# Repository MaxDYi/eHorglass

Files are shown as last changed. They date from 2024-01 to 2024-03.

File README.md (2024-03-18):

# 电子沙漏

# 0 目录

1. 简介
2. 原理图
3. PCB
4. 外壳
5. 物料清单
6. 成本核算
7. 代码实现
8. AT指令

# 1 简介

电子沙漏使用STM32F103C8T6作为主控，利用MPU6050感知当前重力方向。

- 支持使用AT指令对运行参数进行配置。
- 支持更换点阵颜色（更换LED8x8点阵屏）。
- 支持Typec接口充电（内置900mAh锂电池）。



# 2 原理图

eHorglass-SCH-V0.0

# 3 PCB





PCB使用4层板设计，面积4.6x9.2cm，主要元器件位于背面，正面仅有LED8x8点阵屏的圆形排母座。

# 4 外壳

外壳设计详见github库中的**4.Component**部分，共设计**外壳-上**与**外壳-上**两部分，使用3D打印进行实现，利用M3铜柱进行连接。

|  元件 | 尺寸 | 体积 |  表面积 |
| :-----: | :---: | :---: | :---: |
| 外壳-上 | 3.2 * 5.2 * 9.8cm  | 17.72cm³ | 245.49cm² |
| 外壳-下 | 3.45 * 5.2 * 9.8cm | 24.72cm³ | 289.86cm² |

# 5 物料清单

| Comment | Description | Designator | Footprint | Quantity |
| --- | --- | --- | --- | --- |
| 10uF | 贴片电容/MLCC电容 | C1, C2, C10, C12, C13 | C0603_M | 5 |
| 100nF | 贴片电容/MLCC电容 | C3, C4, C5, C6, C7,  C8, C9, C11, C14, C15, C16, C17, C18, C19 | C0603_M | 14 |
| 20pF | 贴片电容/MLCC电容 | C20, C21 | C0603_M | 2 |
| 1N5819 | 肖特基二极管 | D1, D2 | SOD-323 | 2 |
| TP4056 | 锂电池充电管理 | IC1 | SOIC-8_EP | 1 |
| Header 5X2 | 5*2P接插件 | JP1 | HDR2.54-LI-2x5P | 1 |
| HDR-1X2 | 2P接插件 | JP2 | XH2.54-LI-2P | 1 |
| 1588A | 共阴单色LED8*8点阵屏 | LD1, LD2 | LED 8*8-32-FH | 2 |
| RED | 贴片LED | LED1, LED3 | LED0603_R | 2 |
| GREEN | 贴片LED | LED2 | LED0603_G | 1 |
| AO3401 | P沟道 30V/4.2A | Q1 | SOT23-3N | 1 |
| 1K | 贴片电阻 | R1, R3, R11 | R0603_M | 3 |
| 2K | 贴片电阻 | R2 | R0603_M | 1 |
| 10K | 贴片电阻 | R4, R9, R10, R14 | R0603_M | 4 |
| 20K | 贴片电阻 | R5, R6 | R0603_M | 2 |
| 5.1K | 贴片电阻 | R7, R8 | R0603_M | 2 |
| 4.7K | 贴片电阻 | R12, R13 | R0603_M | 2 |
| KCD1-101 | 1路单刀船型开关 | S1 | HDR2.54-LI-2P | 1 |
| M3铜柱 | 铜柱 | SP1, SP2, SP3, SP4 | M3x20+6_N | 4 |
| 3x6x5 | 3x6轻触开关 | SW1 | SW SMD-3*6*2.5  | 1 |
| STM32F103C8T6 | STM32 ARM-based  32-bit MCU | U1 | LQFP48_N | 1 |
| MAX7219 | 8位 LED驱动器 | U2, U3 | SOIC-24W | 2 |
| MPU6050 | 三轴加速度+三轴陀螺仪 | U4 | QFN24-P50 | 1 |
| HT7533 | LDO线性稳压芯片 | U5 | SOT89_N | 1 |
| TYPE-C 2.0  -16P | USB2.0_Type-C_16Pin母座 | USBC1 | USB-C-SMD_16P | 1 |
| 8MHz | 2脚无源晶振(谐振器） | X1 | OSC-5032-2P | 1 |

# 6 成本核算

| 类目 | 型号 | 采购总价 | 采购数量 | 采购单价 | 使用数量 | 小计 |
| :---: | :---: | :---: | :---: | :---: | :---: | :---: |
| PCB |  四层板1.6mm厚 | ¥100.44  | 10 | ¥10.0440 | 1 | ¥10.04 |
| SMT | 经济型 | ¥133.06  | 10 | ¥13.3060 | 1 | ¥13.31 |
|  元器件  | STM32F103C8T6等  |  ¥8.69 | 1 | ¥8.6900  | 1 | ¥46.1 |
| 外壳 | 外壳（黑色树脂） |  ¥9.21 | 1 | ¥9.2100  | 1 | ¥18.50 |
|  固定件  | 尼龙M3固定件 |  ¥6.43 | 100 | ¥0.0643  | 4 | ¥0.67 |
|  锂电池  | 900mAh单节锂电池 |  ¥11.00  | 1 | ¥11.0000 | 1 | ¥11.00 |
| **合计** | | | | | | **¥99.63** |

# 7 代码实现

## 7.1 软件环境

IAR 9.30

STM32CubeMX 6.5.0

## 7.2 主要库

使用到的库位于**\eHorglass\Drivers**路径下。

| 库 | 功能 |
| --- | --- |
| AT | AT指令控制与应答 |
| MAX7219 | 点阵屏驱动库 |
| MPU6050 | MPU6050陀螺仪驱动 |
| parameter | 运行参数配置库 |
| Runtime | 获取代码段运行时间 |
| SandMove  | 砂砾运动控制核心算法 |

## 7.3 砂砾运动控制核心算法

算法流程图如下：

流程图

## 7.4 Flash使用

STM32F103C8T6共64KB内部FLASH，分为64Page，每Page为1KB。



使用前63个FLASH烧录App，最后一个FLash区域用于记录参数。

| 用途 | 地址 | 大小 |
| :---: | :---: | :--: |
| App | 0x08000000 - 0x0800FBFF | 63KB |
| Parameter | 0x0800FC00 - 0x0800FFFF | 1KB  |

最后一个FLash区域记录的参数表如下：

| 参数 | 字节数 |  格式  | 备注 |
| :---: | :----: | :----: | :---: |
| initFlag  | 4 | uint32 | 初始化标志 |
|  sandNum  | 4 | uint32 |  砂砾个数  |
| frameTime | 4 | uint32 | 帧间隔时间 |

# 8 AT指令

支持使用AT指令修改运行参数，可以修改与砂砾个数（SANDNUM）显示帧间隔（FRAMETIME）。

指令分为查询指令与写入指令，均以“**\r\n**”结尾。

## 8.1 使用说明

使用的是STM32的USB虚拟串口实现AT指令，无需设置波特率、数据位、校验位和停止位。

使用时先打开电源开关，再将USB线插入电脑USB口，可以在串口调试助手中读取到“**STMicroelectronics Virtual COM Port**”的串口，如无法打开则尝试重新插拔。

## 8.1 查询指令

查询指令共有3条。

- AT+INFO=?
- AT+SANDNUM=?
- AT+FRAMETIME=?

这3条指令分别返回系统信息、砂砾个数与帧间隔时间。

## 8.2 写入指令

写入指令共有2条。

- AT+SANDNUM=num（AT+SANDNUM=64）
- AT+FRAMETIME=num（AT+FRAMETIME=150）

其中，num为正整数。对于AT+SANDNUM，num的限定值为1-64；对于AT+FRAMETIME，num的限定值为20-1000。

写入后需要重启电源。

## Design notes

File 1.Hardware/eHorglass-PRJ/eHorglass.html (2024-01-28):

Reporting Options

# File in Newer Format

Date | : | 2024/1/27
Time | : | 14:37:39
Project name | : | E:\eHorglass\1.Hardware\eHorglass-PRJ\eHorglass.PrjPcb
Schematic documents | : | eHorglass.SchDoc

Version | Warning
22.3.0 | Custom diff pair suffixes are not supported in this version.

These files were generated in a later version of Altium Designer. Be aware that some data may have been added through functionality not available in your current version and will therefore not be available to you.

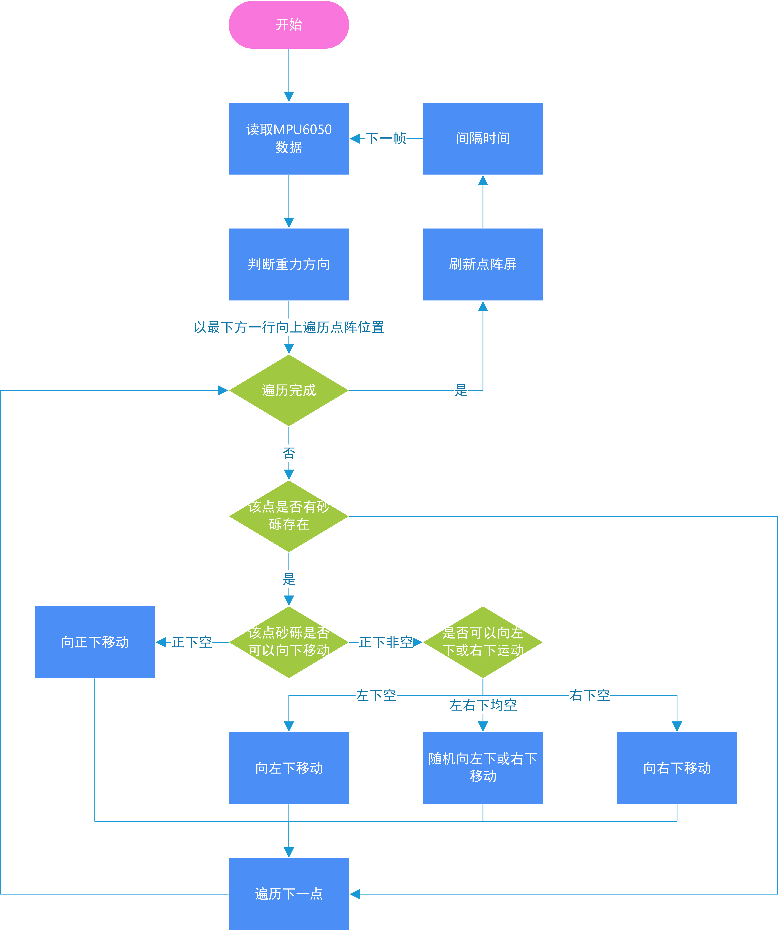
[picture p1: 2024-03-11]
5.Docs/算法流程图/流程图.png

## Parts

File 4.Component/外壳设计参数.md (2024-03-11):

# 外壳设计参数

船型开关开槽9.0x14.0mm

TYPEC开槽10.0x5.0mm

3D打印厚度1.5mm

底部外壳厚4.0mm

上部分外壳厚1.5mm

| 内容 | 高度 |
| --- | --- |
| 铜柱 | 20.0mm |
| 板厚 | 1.6mm  |
| 点阵 | 11.0mm |
| 冗余 | 0.4mm  |
| 上壳厚 | -1.5mm |
| 合计 | 31.5mm |

点阵屏外形尺寸



船型开关参数



TYPE-C接口尺寸



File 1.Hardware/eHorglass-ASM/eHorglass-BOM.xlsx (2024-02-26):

Comment | Description | Designator | Footprint | LibRef | Quantity
10uF | 贴片电容/MLCC电容 | C1, C2, C10, C12, C13 | C0603_M | C | 5
100nF | 贴片电容/MLCC电容 | C3, C4, C5, C6, C7, C8, C9, C11, C14, C15, C16, C17, C18, C19 | C0603_M | C | 14
20pF | 贴片电容/MLCC电容 | C20, C21 | C0603_M | C | 2
1N5819 | 肖特基二极管 | D1, D2 | SOD-323 | 1N5819 | 2
TP4056 | 锂电池充电管理 | IC1 | SOIC-8_EP | TP4056 | 1
Header 5X2 | 5*2P接插件 | JP1 | HDR2.54-LI-2x5P | Header 5X2 | 1
HDR-1X2 | 2P接插件 | JP2 | XH2.54-LI-2P | Header 2 | 1
1588A | 共阴单色LED8*8点阵屏 | LD1, LD2 | LED 8*8-32-FH | 1588A | 2
RED | 贴片LED | LED1, LED3 | LED0603_R | LED | 2
GREEN | 贴片LED | LED2 | LED0603_G | LED | 1
AO3401 | P沟道 30V/4.2A | Q1 | SOT23-3N | AO3401 | 1
1K | 贴片电阻 | R1, R3, R11 | R0603_M | R | 3
2K | 贴片电阻 | R2 | R0603_M | R | 1
10K | 贴片电阻 | R4, R9, R10, R14 | R0603_M | R | 4
20K | 贴片电阻 | R5, R6 | R0603_M | R | 2
5.1K | 贴片电阻 | R7, R8 | R0603_M | R | 2
4.7K | 贴片电阻 | R12, R13 | R0603_M | R | 2
1K5 | 贴片电阻 | R15 | R0603_M | R | 1
22R | 贴片电阻 | R16, R17 | R0603_M | R | 2
KCD1-101 | 1路单刀船型开关 | S1 | HDR2.54-LI-2P | KCD1-101 | 1
M3铜柱 | 铜柱 | SP1, SP2, SP3, SP4 | M3x20+6_N | 铜柱加头大焊盘 | 4
3x6x5 | 3x6轻触开关 | SW1 | SW SMD-3*6*2.5 | SW 3x6 | 1
STM32F103C8T6 | STM32 ARM-based 32-bit MCU Performance Line with 64 kB Flash, 20 kB Internal RAM, -40 to +85癈 Temperature, 48-Pin LQFP, Tray | U1 | LQFP48_N | STM32F103C8T6 | 1
MAX7219 | 8位 LED驱动器 | U2, U3 | SOIC-24W | MAX7219 | 2
MPU6050 | 三轴加速度+三轴陀螺仪 | U4 | QFN24-P50 | MPU6050 | 1
HT7533 | LDO线性稳压芯片 | U5 | SOT89_N | HT7533 | 1
TYPE-C 2.0 -16P | USB2.0_Type-C_16Pin母座 | USBC1 | USB-C-SMD_16P | USB2.0_Type-C_16Pin | 1
8MHz | 2脚无源晶振(谐振器） | X1 | OSC-5032-2P | XTAL-2P | 1

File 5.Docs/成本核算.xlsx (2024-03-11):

类目 | 型号 | 采购总价 | 采购数量 | 采购单价 | 使用数量 | 小计
PCB | 四层板1.6mm | ¥100.44 | 10 | ¥10.0440 | 1 | ¥10.04 | ¥10.04
SMT | 经济型 | ¥133.06 | 10 | ¥13.3060 | 1 | ¥13.31 | ¥13.31
元器件 | STM32F103C8T6 | ¥8.69 | 1 | ¥8.6900 | 1 | ¥8.69
 | MPU6050 | ¥600.00 | 50 | ¥12.0000 | 1 | ¥12.00
 | TP4056X | ¥1.15 | 1 | ¥1.1500 | 1 | ¥1.15
 | MAX7219 | ¥261.60 | 40 | ¥6.5400 | 2 | ¥13.08
 | LED点阵屏 | ¥2.00 | 1 | ¥2.0000 | 2 | ¥4.00
 | 8M Xtal | ¥1.13 | 1 | ¥1.1300 | 1 | ¥1.13
 | 其他 | ¥60.54 | 10 | ¥6.0540 | 1 | ¥6.05 | ¥46.10
外壳 | 外壳-上（白） | ¥9.21 | 1 | ¥9.2100 | 0 | ¥0.00
 | 外壳-下（白） | ¥12.85 | 1 | ¥12.8500 | 0 | ¥0.00
 | 外壳-上（黑） | ¥7.80 | 1 | ¥7.8000 | 1 | ¥7.80
 | 外壳-下（黑） | ¥10.70 | 1 | ¥10.7000 | 1 | ¥10.70 | ¥18.50
固定件 | 尼龙柱M3*20+6 | ¥6.43 | 100 | ¥0.0643 | 4 | ¥0.26
 | 尼龙沉头螺丝M3*10 | ¥5.42 | 100 | ¥0.0542 | 4 | ¥0.22
 | 尼龙螺母M3 | ¥5.00 | 100 | ¥0.0500 | 4 | ¥0.20 | ¥0.67
锂电池 | 900mAh单节锂电池 | ¥11.00 | 1 | ¥11.0000 | 1 | ¥11.00
 | 1800mAh单节锂电池 | ¥18.80 | 1 | ¥18.8000 | 0 | ¥0.00 | ¥11.00
合计 |  |  |  |  |  | ¥99.63

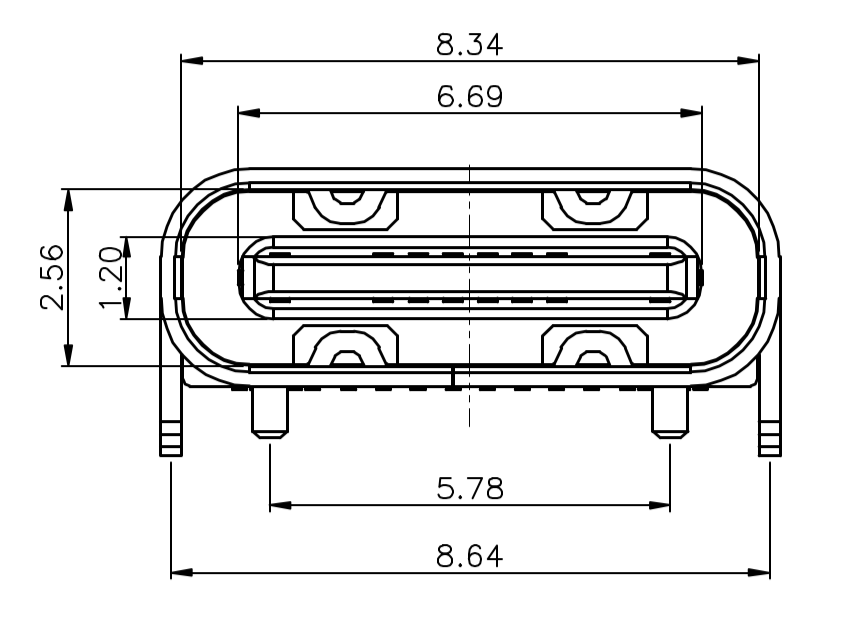
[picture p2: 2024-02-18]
4.Component/参考设计图/Typec接口.png

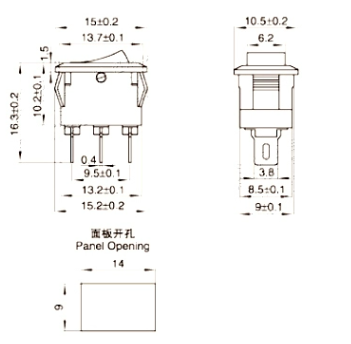
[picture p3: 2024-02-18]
4.Component/参考设计图/船型开关.png

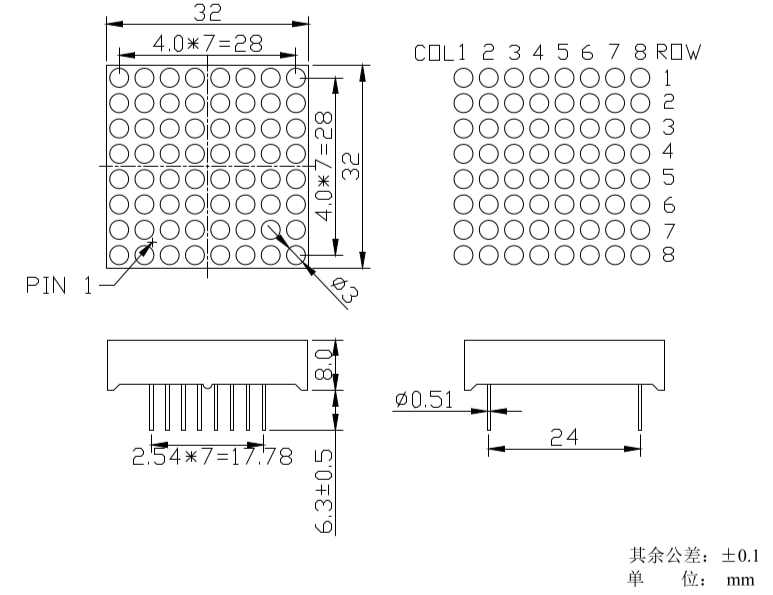
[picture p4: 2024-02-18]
4.Component/参考设计图/LED8x8点阵.png

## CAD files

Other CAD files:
4.Component/LED 8x8点阵32mm带排母/HDR2.54圆形排母1x8P.step
4.Component/PCB/PCB.SLDPRT
4.Component/外壳/外壳-上.STEP
4.Component/船型开关/船型开关.STEP
4.Component/LED 8x8点阵32mm带排母/LED 8x8点阵32mm.STEP
4.Component/外壳/外壳-下.STEP
4.Component/LED 8x8点阵32mm带排母/HDR2.54排母1x8P.STEP
4.Component/LED 8x8点阵32mm带排母/HDR2.54圆形排母1x8P.SLDPRT
4.Component/LED 8x8点阵32mm带排母/HDR2.54排母1x8P.SLDPRT
4.Component/LED 8x8点阵32mm带排母/LED 8x8点阵32mm.SLDPRT
4.Component/外壳/外壳-上.SLDPRT
4.Component/外壳/外壳-下.SLDPRT
4.Component/船型开关/船型开关.SLDPRT

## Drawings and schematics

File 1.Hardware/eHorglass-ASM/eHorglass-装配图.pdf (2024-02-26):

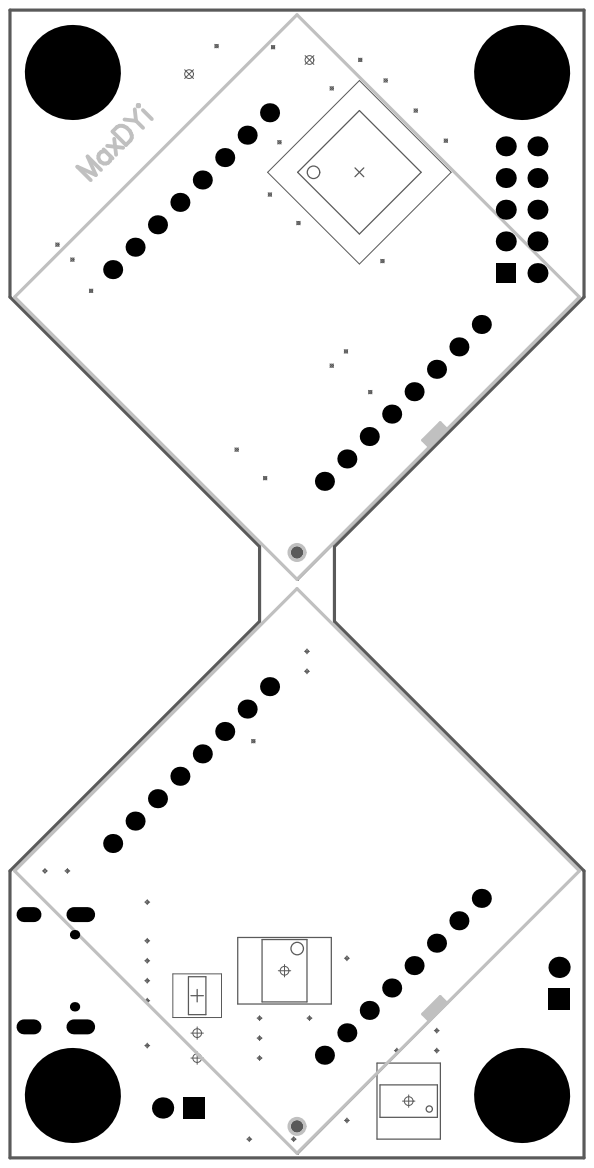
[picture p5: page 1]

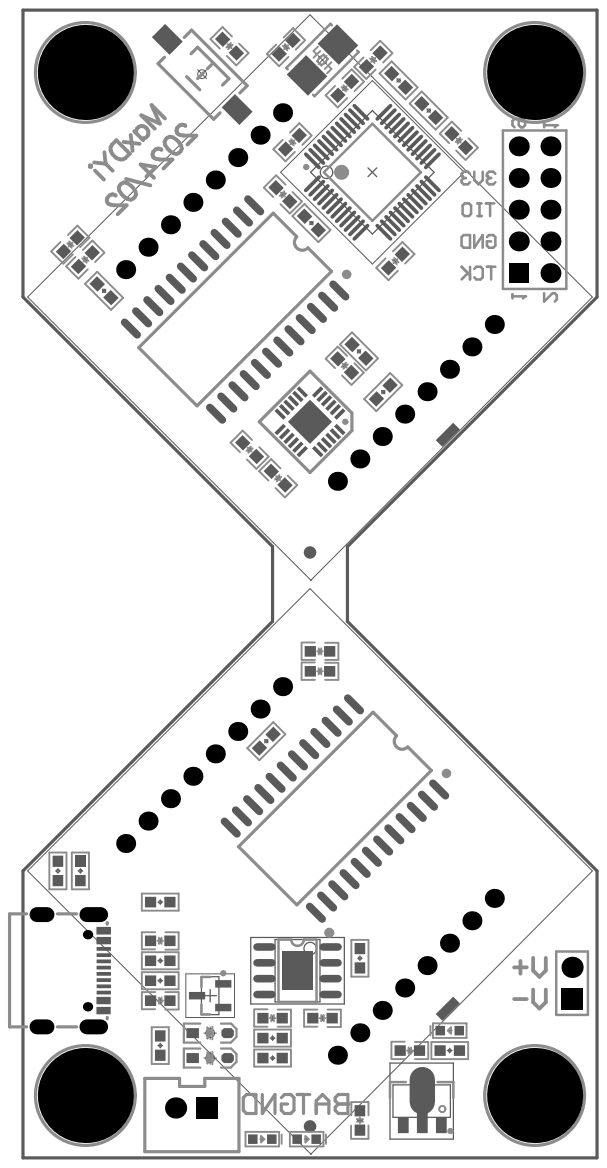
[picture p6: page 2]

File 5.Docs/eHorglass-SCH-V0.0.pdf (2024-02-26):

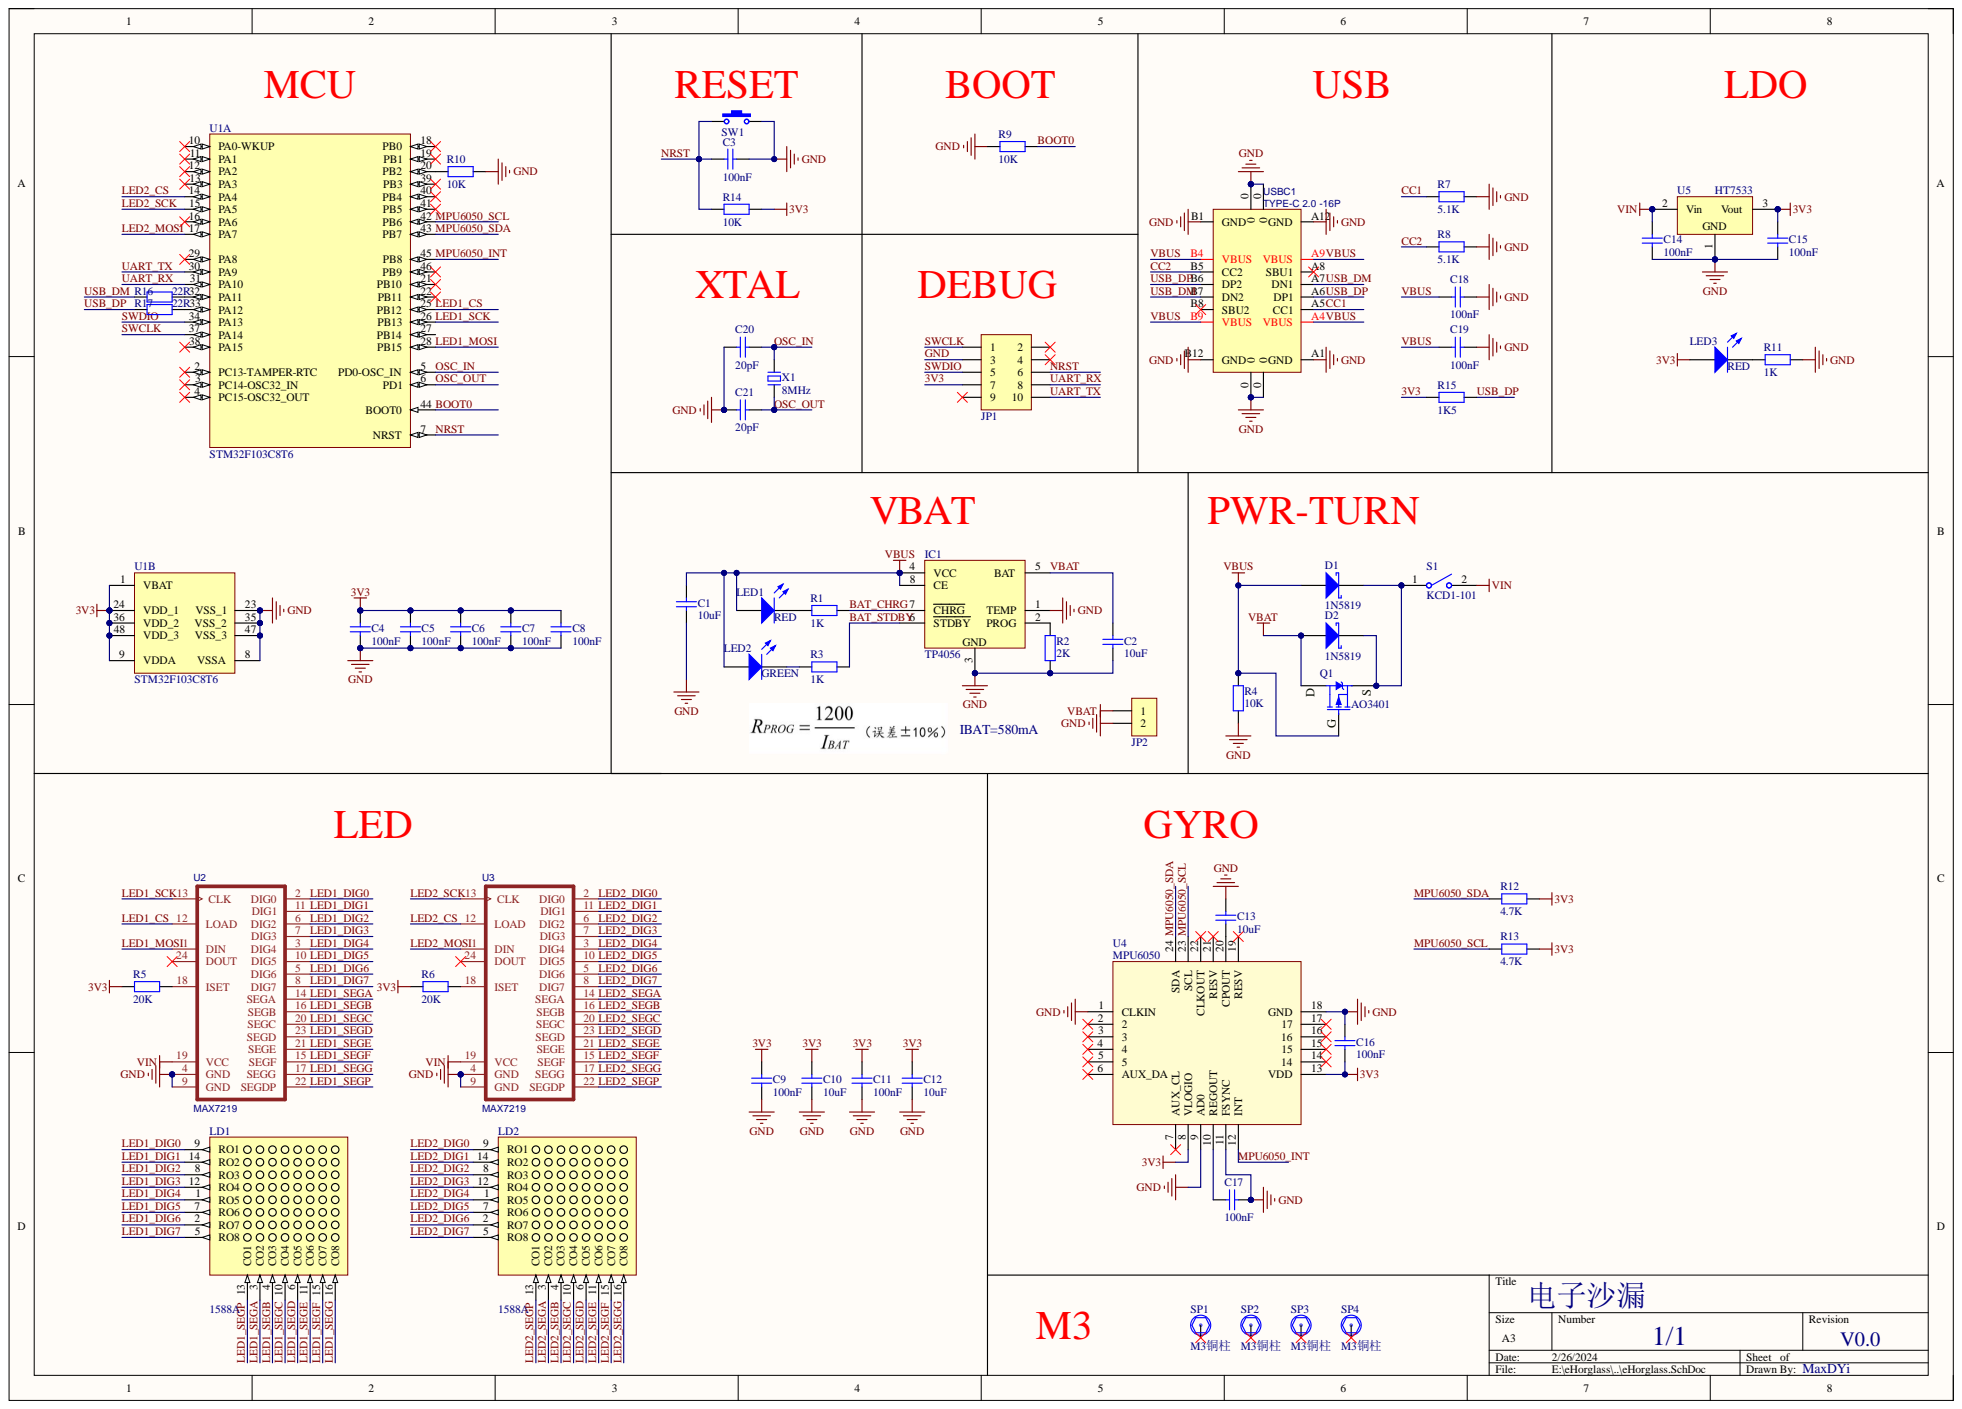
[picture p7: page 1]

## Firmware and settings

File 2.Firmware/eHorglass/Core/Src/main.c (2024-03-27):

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
/* Includes ------------------------------------------------------------------*/
#include "main.h"
#include "adc.h"
#include "dma.h"
#include "i2c.h"
#include "spi.h"
#include "tim.h"
#include "usart.h"
#include "usb_device.h"
#include "gpio.h"

/* USER CODE BEGIN Includes */
#include "usbd_cdc_if.h"
#include "stdio.h"
#include "stdlib.h"
#include "string.h"
#include "spi.h"
#include "MAX7219.h"
#include "MPU6050.h"
#include "common.h"
#include "SandMove.h"
#include "Runtime.h"
#include "AT.h"
#include "Parameter.h"
/* USER CODE END Includes */

/* USER CODE BEGIN PTD */
#define UART_BUFFER_SIZE 256
/* USER CODE END PTD */

/* USER CODE BEGIN PM */
struct parameters runPara;
uint8_t ledScreen1[LED_WIDTH * LED_WIDTH];
uint8_t ledScreen2[LED_WIDTH * LED_WIDTH];
uint8_t ledScreenData1[LED_WIDTH];
uint8_t ledScreenData2[LED_WIDTH];
uint8_t Uart_Buffer[UART_BUFFER_SIZE];
/* USER CODE END PM */


/* USER CODE BEGIN PV */
void HAL_UARTEx_RxEventCallback(UART_HandleTypeDef* huart, uint16_t Size)
{
    if (huart == &huart1)
    {
        AT_ParseCommand(Uart_Buffer);
        memset(Uart_Buffer, 0, UART_BUFFER_SIZE);
        HAL_UARTEx_ReceiveToIdle_DMA(&huart1, Uart_Buffer, UART_BUFFER_SIZE);
    }
}
/* USER CODE END PV */

void SystemClock_Config(void);
/**
  * @brief  The application entry point.
  * @retval int
  */
int main(void)
{
  /* MCU Configuration--------------------------------------------------------*/

  /* Reset of all peripherals, Initializes the Flash interface and the Systick. */
  HAL_Init();

  /* Configure the system clock */
  SystemClock_Config();

  /* Initialize all configured peripherals */
  MX_GPIO_Init();
  MX_DMA_Init();
  MX_I2C1_Init();
  MX_SPI1_Init();
  MX_SPI2_Init();
  MX_USART1_UART_Init();
  MX_USB_DEVICE_Init();
  MX_ADC1_Init();
  MX_TIM3_Init();
  /* USER CODE BEGIN 2 */
    
    max7219_handle led1_handle;
    max7219_handle led2_handle;
    led1_handle.spiHandle = &hspi1;
    led1_handle.CS_GPIO = LED1_CS_GPIO_Port;
    led1_handle.CS_Pin = LED1_CS_Pin;
    led2_handle.spiHandle = &hspi2;
    led2_handle.CS_GPIO = LED2_CS_GPIO_Port;
    led2_handle.CS_Pin = LED2_CS_Pin;
    Max7219_Init(led1_handle);
    Max7219_Init(led2_handle);
    Max7219_DisplayNromal(led1_handle);
    Max7219_DisplayNromal(led2_handle);
  
    LoadParameters(&runPara);
    AT_Init(&runPara);
    Runtime_Init();
    HAL_ADC_Start(&hadc1);
    HAL_ADC_PollForConversion(&hadc1, 50);
    uint16_t ADC_vaule = HAL_ADC_GetValue(&hadc1);
    
    MPU6050_Init();
    while(MPU6050ReadID() == 0){
      MPU6050_Init();
      HAL_Delay(200);
    }
    
    srand(ADC_vaule);

    HAL_Delay(200);
    uint8_t gDirection = MPU6050_GetDirection(0);
    
    for (uint8_t i = 0;i < LED_WIDTH * LED_WIDTH;i++) {
        ledScreen1[i] = EMPTY;
        ledScreen2[i] = EMPTY;
    }
    if (Sand_GetUpLed(gDirection) == LED_SCREEN_1) {
        for (uint8_t i = 0;i < runPara.sandNum;i++) {
            coord xy = Sand_GetLoopCoord(i, gDirection, LEFT);
            ledScreen1[xy.x * LED_WIDTH + xy.y] = FULL;
        }
    }
    else {
        for (uint8_t i = 0;i < runPara.sandNum;i++) {
            coord xy = Sand_GetLoopCoord(i, gDirection, LEFT);
            ledScreen2[xy.x * LED_WIDTH + xy.y] = FULL;
        }
    }

    memset(Uart_Buffer, 0, UART_BUFFER_SIZE);
    HAL_UARTEx_ReceiveToIdle_DMA(&huart1, Uart_Buffer, UART_BUFFER_SIZE);
    
    Max7219_Display(led1_handle, 0, ledScreenData1);
    Max7219_Display(led2_handle, 0, ledScreenData2);
  /* USER CODE END 2 */

  /* Infinite loop */
  /* USER CODE BEGIN WHILE */
    while (1)
    {
    /* USER CODE END WHILE */

    /* USER CODE BEGIN 3 */

        Runtime_Start();

        gDirection = MPU6050_GetDirection(0);

        uint8_t upLED = Sand_GetUpLed(gDirection);
        uint8_t downLED = Sand_GetDownLed(gDirection);
        uint8_t* nowScreen = NULL;
        uint8_t* nextScreen = NULL;
        uint8_t nowLEDNum = downLED;
        for (uint8_t i = 0;i < LED_WIDTH;i++) {
            for (uint8_t j = 0;j < LED_WIDTH;j++) {
                if (upLED == LED_SCREEN_1) {
                    nowScreen = ledScreen2;
                    nextScreen = ledScreen1;
                }
                else {
                    nowScreen = ledScreen1;
                    nextScreen = ledScreen2;
                }
            }
        }

        Sand_UpdateScreen(nowScreen, nextScreen, nowLEDNum, runPara.sandNum, gDirection);
        nowLEDNum = 1 - nowLEDNum;
        Sand_UpdateScreen(nextScreen, nowScreen, nowLEDNum, runPara.sandNum, gDirection);

        for (uint8_t i = 0;i < LED_WIDTH;i++) {
            uint8_t ledBuf1 = 0;
            uint8_t ledBuf2 = 0;
            for (uint8_t j = 0;j < LED_WIDTH;j++) {
                ledBuf1 = ledBuf1 + (ledScreen1[i * LED_WIDTH + j] << j);
                ledBuf2 = ledBuf2 + (ledScreen2[i * LED_WIDTH + j] << j);
            }
            ledScreenData1[i] = ledBuf1;
            ledScreenData2[i] = ledBuf2;
        }
        Max7219_Display(led1_handle, 0, ledScreenData1);
        Max7219_Display(led2_handle, 0, ledScreenData2);
        uint32_t codeRuntime = Runtime_Stop() / 1000;
        if (codeRuntime < runPara.frameTime) {
            HAL_Delay(runPara.frameTime - codeRuntime);
        }
        //HAL_GPIO_TogglePin(TEST_GPIO_Port, TEST_Pin);
    }
  /* USER CODE END 3 */
}

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


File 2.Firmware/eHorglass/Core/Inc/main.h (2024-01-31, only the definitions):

#define LED1_CS_Pin GPIO_PIN_4
#define LED1_CS_GPIO_Port GPIOA
#define LED1_SCK_Pin GPIO_PIN_5
#define LED1_SCK_GPIO_Port GPIOA
#define LED1_MOSI_Pin GPIO_PIN_7
#define LED1_MOSI_GPIO_Port GPIOA
#define LED2_CS_Pin GPIO_PIN_12
#define LED2_CS_GPIO_Port GPIOB
#define LED2_SCK_Pin GPIO_PIN_13
#define LED2_SCK_GPIO_Port GPIOB
#define LED2_MOSI_Pin GPIO_PIN_15
#define LED2_MOSI_GPIO_Port GPIOB
#define SWDIO_Pin GPIO_PIN_13
#define SWDIO_GPIO_Port GPIOA
#define SWCLK_Pin GPIO_PIN_14
#define SWCLK_GPIO_Port GPIOA
#define MPU6050_SCL_Pin GPIO_PIN_6
#define MPU6050_SCL_GPIO_Port GPIOB
#define MPU6050_SDA_Pin GPIO_PIN_7
#define MPU6050_SDA_GPIO_Port GPIOB
#define MPU6050_INT_Pin GPIO_PIN_8
#define MPU6050_INT_GPIO_Port GPIOB

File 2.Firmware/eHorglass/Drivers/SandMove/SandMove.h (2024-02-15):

/*
 * @Description  :
 * @Author       : MaxDYi
 * @Date         : 2024-02-04 20:48:36
 * @LastEditTime : 2024-02-15 13:21:42
 * @FilePath     : \ArcheryTimer_Appe:\eHorglass\2.Firmware\eHorglass\Drivers\SandMove\SandMove.h
 */
#ifndef __SANDMOVE_H__
#define __SANDMOVE_H__

#include "common.h"
#include "time.h"

#define LED_WIDTH 8
#define SAND_MAX_NUM (LED_WIDTH*LED_WIDTH)

#define LED_SCREEN_1 0
#define LED_SCREEN_2 1

#define EMPTY 0
#define FULL 1

#define OUT 0
#define IN 1

#define MID 0
#define LEFT 1
#define RIGHT 2

typedef struct
{
    int x;
    int y;
}coord;

coord Sand_GetLoopCoord(uint8_t index, uint8_t direction, uint8_t moveOrder);

void Sand_GetTarget(coord now_xy, coord* target_xy, uint8_t direction);

uint8_t Sand_GetUpLed(uint8_t gDirection);

uint8_t Sand_GetDownLed(uint8_t gDirection);

uint8_t Sand_IsBorder(int x);

uint8_t Sand_IsVertex(coord target_xy, uint8_t direction);

uint8_t Sand_IsDownVertex(coord target_xy, uint8_t direction);

uint8_t Sand_IsUpVertex(coord target_xy, uint8_t direction);

uint8_t Sand_TargetIsEmpty(coord target_xy, uint8_t nowLEDNum, uint8_t direction, uint8_t* now_screen, uint8_t* next_screen);

void Sand_MoveToTarget(coord now_xy, coord target_xy, uint8_t direction, uint8_t nowLEDNum, uint8_t* now_screen, uint8_t* next_screen);

void Sand_UpdateScreen(uint8_t* nowScreen, uint8_t* nextScreen, uint8_t nowLEDNum, uint8_t sandNum, uint8_t gDirection);

#endif

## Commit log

2023-12-27 电子沙漏V0.0.0
    [Fabrication Testpoint Report for eHorglass.csv, eHorglass-BOM.xlsx, eHorglass-坐标文件.csv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]
2023-12-30 MAX7219硬件SPI驱动
2023-12-30 添加LED点阵方向翻转代码
2023-12-30 max7219驱动
2023-12-31 STM32F411CEU6开发板测试
2024-01-01 下单制作
2024-01-08 外壳-上部分完成
    [外壳-上.SLDPRT, 外壳-上.STEP, 外壳-下.SLDPRT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]
2024-01-08 铜柱修改为M3*10
    [eHorglass-BOM.xlsx, eHorglass.SchDoc]
2024-01-08 外壳下部分完成底面
    [外壳-下.SLDPRT]
2024-01-11 pcb中seg引脚错误，修正原理图，未修正PCB
    [eHorglass-BOM.xlsx, eHorglass.SchDoc]
2024-01-11 MPU6050测试正常，内部flash读写参数正常
2024-01-23 修改电路图，MAX7219改为电池与USB供电，修正错误的LED引脚。
    [Fabrication Testpoint Report for eHorglass.csv, eHorglass-BOM.xlsx, eHorglass-坐标文件.csv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]
2024-01-23 MAX7219参考电路图
2024-01-23 STM32F103参考手册
2024-01-23 01月23日小修改
2024-01-25 修改README
2024-01-28 PCB底板模型
    [PCB.SLDPRT, PCB.step]
2024-01-28 船型开关3D模型
    [船型开关.SLDPRT, 船型开关.STEP]
2024-01-28 HDR2.54排母1x8P模型
    [HDR2.54排母1x8P.SLDPRT, HDR2.54排母1x8P.STEP]
2024-01-28 LED 8x8点阵32mm模型
    [LED 8x8点阵32mm.SLDPRT, LED 8x8点阵32mm.STEP]
2024-01-28 删除错误设计
    [外壳-上.SLDPRT, 外壳-上.STEP, 外壳-下.SLDPRT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]
2024-01-28 修改铜柱长度
    [eHorglass-BOM.xlsx, eHorglass-坐标文件.csv, eHorglass.PrjPcb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]
2024-01-28 替换MAX7219手册
2024-01-28 删除TP4056手册
2024-01-28 铜柱长度修改为M3*20+6
    [eHorglass-BOM.xlsx, eHorglass-坐标文件.csv, eHorglass.PrjPcb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]
2024-01-28 修改LED点阵3D模型高度
    [eHorglass.PrjPcb]
2024-01-28 添加TYPEC接口手册
2024-01-28 修改点阵3D模型
    [PCB.SLDPRT, PCB.step]
2024-01-28 外壳-下设计文件
    [外壳-下.SLDPRT, 外壳-下.STEP]
2024-01-28 添加设计参数文件
2024-01-28 缺少TYPEC口开槽
    [外壳-上.SLDPRT]
2024-01-31 启用FreeRTOS
2024-01-31 降低高度0.6mm
    [外壳-上.SLDPRT, 外壳-上.STEP, 外壳-下.SLDPRT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]
2024-01-31 TYPEC口外移0.4mm
    [PCB.SLDPRT]
2024-01-31 充电电流调整至400mA
    [eHorglass-BOM.xlsx, eHorglass-坐标文件.csv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]
2024-02-02 削减底壳非连接部分厚度
    [外壳-下.SLDPRT, 外壳-下.STEP]
2024-02-04 2月4日存档
2024-02-05 添加HDR2.54圆形排母1x8P手册
2024-02-05 添加HDR2.54圆形排母1x8P模型
    [HDR2.54圆形排母1x8P.SLDPRT, HDR2.54圆形排母1x8P.step]
2024-02-05 替换为圆形排母的PCB模型
    [PCB.SLDPRT]
2024-02-05 将方形排母替换为圆形排母
2024-02-05 高度修改为31.5mm外壳
    [外壳-上.SLDPRT, 外壳-上.STEP, 外壳-下.SLDPRT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]
2024-02-05 TYPEC接口外移1mm
    [eHorglass-BOM.xlsx, eHorglass-坐标文件.csv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]
2024-02-05 连接点附近粒子运动方向不正确
2024-02-05 倒置无法通过中间部分
2024-02-06 倒置下落正常
2024-02-06 修复RST上拉电阻缺失的问题
    [eHorglass-BOM.xlsx, eHorglass-坐标文件.csv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]
2024-02-06 添加上拉电阻R14后的3D模型
    [PCB.SLDPRT]
2024-02-06 为SandMove库添加注释
2024-02-15 实现参数写入内部Flash
2024-02-15 移植AT指令
2024-02-15 添加FrameTime的极限值
2024-02-16 修复无法复位问题
2024-02-16 添加成本核算
    [成本核算.xlsx]
2024-02-16 启用USB功能
2024-02-16 添加STM32F103C8用户手册
2024-02-16 修改充电限流电阻至3KΩ
    [eHorglass-BOM.xlsx, eHorglass-坐标文件.csv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]
2024-02-16 修改充电限流电阻至3K后的电路图
2024-02-18 添加参考设计图
2024-02-18 添加设计说明
2024-02-19 修改高度至31.5mm
    [外壳-上.SLDPRT, 外壳-上.STEP, 外壳-下.SLDPRT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]
2024-02-19 删除角度校准指令
2024-02-19 修复MPU6050有时初始化失败的问题
2024-02-26 添加USB相关电阻R15、R16、R17
    [PCB.SLDPRT, eHorglass-BOM.xlsx, eHorglass-坐标文件.csv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]
2024-03-11 修改成本核算
    [成本核算.xlsx]
2024-03-11 核心算法流程图
2024-03-11 3月11日版本固件
2024-03-11 添加算法流程说明
2024-03-11 更换新版原理图
2024-03-11 增大TYPEC开槽厚度至5.0mm
    [外壳-上.SLDPRT, 外壳-上.STEP, 外壳-下.SLDPRT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]
2024-03-18 减小typec开口
    [外壳-上.STEP]
2024-03-18 3月18日存档
    [外壳-上.SLDPRT]
2024-03-27 修复了在180度时判断错误方向的问题

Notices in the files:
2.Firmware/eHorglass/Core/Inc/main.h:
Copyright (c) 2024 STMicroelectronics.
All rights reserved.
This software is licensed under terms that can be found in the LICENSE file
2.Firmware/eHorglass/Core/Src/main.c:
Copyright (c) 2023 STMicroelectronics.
